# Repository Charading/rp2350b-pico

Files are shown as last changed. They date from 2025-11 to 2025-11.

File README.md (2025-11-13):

# RP2350B Pico Board

This is a custom RP2350B development board designed to match the **Raspberry Pi Pico** form factor.  
It keeps a similar form factor but is extended by a few pins, in order to break out all 8 analog gpio.

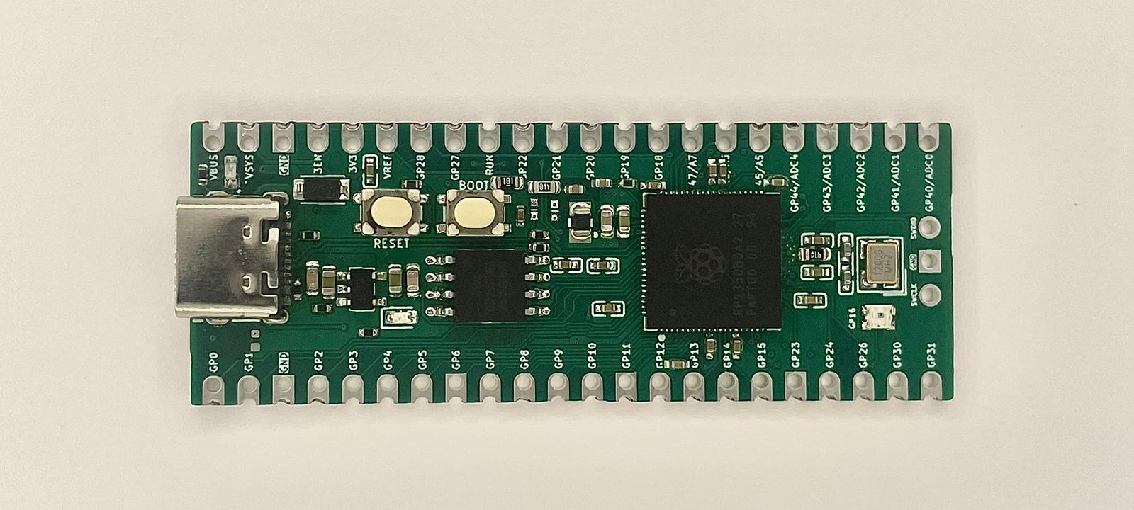
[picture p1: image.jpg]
assembled board


---

## Features
- **RP2350B microcontroller**
- **Pico-compatible pinout**
- **USB-C connector**
- **WS2812 RGB LED** on **GPIO16**
- **BOOT** and **RESET** buttons
- **Castellated edges** for module or breadboard use

---

## Notes
- The WS2812 LED on **GPIO16** can be controlled using any standard NeoPixel or WS2812 library.
- The board powers from **USB 5V (VBUS)** through a Schottky diode to **VSYS**,  
  then regulated down to **3.3V** for the MCU.
- Fully compatible with the **Raspberry Pi Pico SDK**, **MicroPython**, and **CircuitPython**.

### Expansion Board
I also created a small expansion board since it doesn't follow the exact layout as the original Pico.

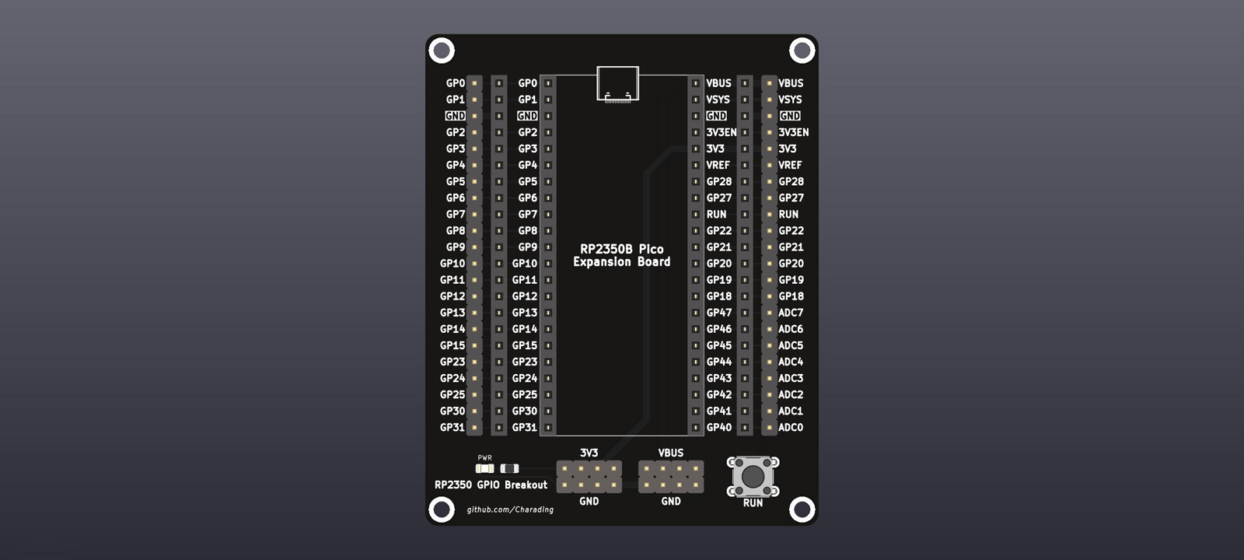
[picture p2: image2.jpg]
expansion board


---

Designed for experimentation and easy migration from RP2040 to RP2350 as I wanted more analog pins for a project.
Inspiration taken from  [pico-stretch](https://github.com/jvanderberg/pico-stretch) by [jvanderberg](https://github.com/jvanderberg)

---

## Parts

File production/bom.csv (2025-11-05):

Designator | Footprint | Quantity | Value | LCSC Part #
BOOT1, RESET1 | KEY-SMD_4P-L4.2-W3.2-P2.20-LS5.1-TL | 2 | K2-1808SN-A4SW-01 | C92589
C1, C13, C14, C16, C2, C36, C7, C8 | C0402 | 8 | 100nF | C1525
C10, C12 | C_0603 | 2 | 4.7uF | C19666
C11, C19 | C_0402 | 2 | 4.7uF | C23733
C15, C9 | C0402 | 2 | 100nF | C14663
C17, C18 | C0402 | 2 | 15pF | C1548
C22 | C_0402 | 1 | 100nF | C1525
C3, C4, C5, C6 | C0402 | 4 | 100nF
C37, C40 | C_0603 | 2 | 10uF | C19702
C38, C39 | C_0603 | 2 | 100nF | C14663
D1 | POWERDI-123_L2.8-W1.8-LS3.7-RD | 1 | ~ | C110493
D2, D3 | D0402-BI | 2 | RCLAMP0521P.TCT-MS | C3029033
D4 | LED_WS2812B-2020_PLCC4_2.0x2.0mm | 1 | WS2812B-2020
J1, J3 | Pico_22pin | 2 | Conn_01x32_MountingPin
J2 | PinHeader_1x03_P2.54mm_Vertical | 1 | Conn_01x03_Pin
L1 | IND-SMD_L2.0-W1.6_AOTA-B201610S3R3-101-T | 1 | ~ | C42411119
LED1 | Mars_LED_0603 | 1 | Red | C2286
PWR_LED1 | D_0603 | 1 | Red | C2286
R1, R4 | R_0402 | 2 | 5.1kΩ | C25905
R11 | R_0402 | 1 | 100kΩ | C25741
R12, R9 | R_0402 | 2 | 2kΩ | C4109
R14 | R_0402 | 1 | 10kΩ | C25744
R2, R3 | R_0402 | 2 | 33Ω | C25105
R28 | R_0603 | 1 | 1kΩ | C21190
R5 | R_0402 | 1 | 1kΩ | C11702
R6 | R0402 | 1 | 33Ω | C25105
R7 | R_0603 | 1 | 1Ω | C22936
R8 | R_0603 | 1 | 200Ω | C8218
TP1, TP2 | TestPoint_Pad_1.0x1.0mm | 2 | TestPoint
U1 | QFN-80_L10.0-W10.0-P0.40-TL-EP3.4 | 1 | ~ | C42415655
U3 | SOT-23-5_L3.0-W1.7-P0.95-LS2.8-BR | 1 | ~ | C427602
U4 | SOIC-8_L5.3-W5.3-P1.27-LS8.0-BL | 1 | Winbond W25Q128JVSIQ | C97521
U6 | SOIC-8_3.9x4.9mm_P1.27mm | 1 | ESP-PSRAM32
USB1 | USB-C-SMD_TYPE-C-6PIN-2MD-073 | 1 | ~ | C2765186
X1 | CRYSTAL-SMD_4P-L3.2-W2.5-BL | 1 | ~ | C20625731

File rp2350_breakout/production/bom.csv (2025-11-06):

Designator | Footprint | Quantity | Value | LCSC Part #
J1, J2, J3, J4, J5, J6 | Mars_Clean_Connector_01x22_PinHeader_2.54mm | 6 | Conn_01x32_MountingPin
PWR | 0805 | 1 | LED
R1 | R_0805 | 1 | R
SW1 | SW_TH_Tactile_Omron_B3F-102x | 1 | RUN

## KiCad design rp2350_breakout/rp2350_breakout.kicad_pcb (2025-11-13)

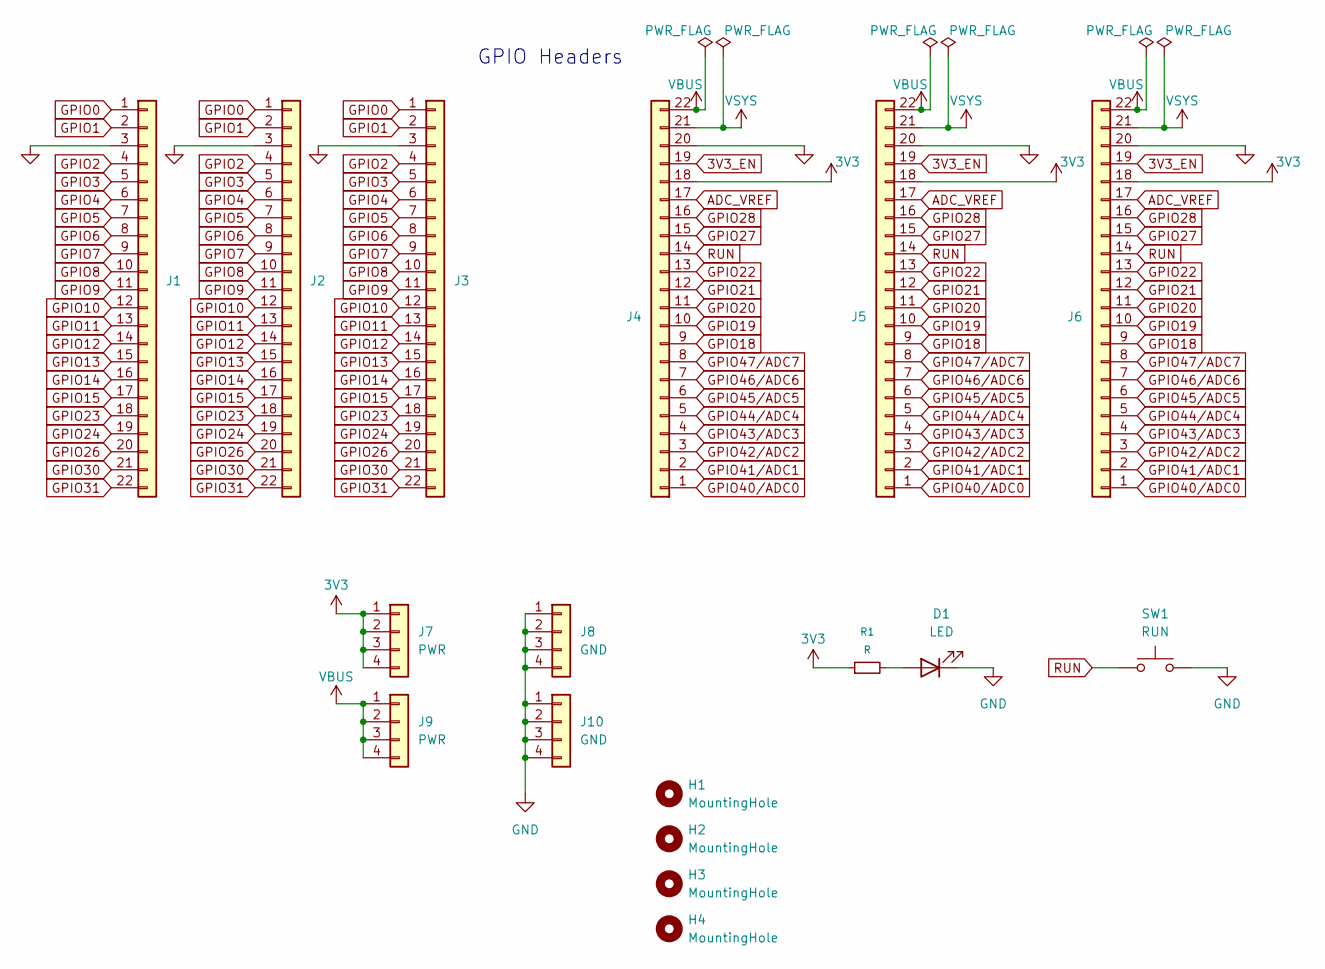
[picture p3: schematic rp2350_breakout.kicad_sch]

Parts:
D1: LED; LED_0805_2012Metric
H1, H2, H3, H4: MountingHole; MountingHole_2.2mm_M2
J1, J2, J3, J4, J5, J6: Conn_01x32_MountingPin; Mars_Clean_Connector_01x22_PinHeader_2.54mm
J7, J9: PWR; SWD_Debug_PinHeader_1x04_P2.54mm; Part Number 1-0401FBV0T
J8, J10: GND; SWD_Debug_PinHeader_1x04_P2.54mm; Part Number 1-0401FBV0T
R1: R; R_0805
SW1: RUN; SW_TH_Tactile_Omron_B3F-102x

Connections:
3V3: J4.18, J5.18, J6.18, J7.1, J7.2, J7.3, J7.4, R1.1
3V3_EN: J4.19, J5.19, J6.19
ADC_VREF: J4.17, J5.17, J6.17
GND: D1.1 (K), J1.3, J2.3, J3.3, J4.20, J5.20, J6.20, J8.1, J8.2, J8.3, J8.4, J10.1, J10.2, J10.3, J10.4, SW1.2; also elsewhere on the board
GPIO0: J1.1, J2.1, J3.1
GPIO1: J1.2, J2.2, J3.2
GPIO2: J1.4, J2.4, J3.4
GPIO3: J1.5, J2.5, J3.5
GPIO4: J1.6, J2.6, J3.6
GPIO5: J1.7, J2.7, J3.7
GPIO6: J1.8, J2.8, J3.8
GPIO7: J1.9, J2.9, J3.9
GPIO8: J1.10, J2.10, J3.10
GPIO9: J1.11, J2.11, J3.11
GPIO10: J1.12, J2.12, J3.12
GPIO11: J1.13, J2.13, J3.13
GPIO12: J1.14, J2.14, J3.14
GPIO13: J1.15, J2.15, J3.15
GPIO14: J1.16, J2.16, J3.16
GPIO15: J1.17, J2.17, J3.17
GPIO18: J4.9, J5.9, J6.9
GPIO19: J4.10, J5.10, J6.10
GPIO20: J4.11, J5.11, J6.11
GPIO21: J4.12, J5.12, J6.12
GPIO22: J4.13, J5.13, J6.13
GPIO23: J1.18, J2.18, J3.18
GPIO24: J1.19, J2.19, J3.19
GPIO26: J1.20, J2.20, J3.20
GPIO27: J4.15, J5.15, J6.15
GPIO28: J4.16, J5.16, J6.16
GPIO30: J1.21 (Pin_19), J2.21 (Pin_19), J3.21 (Pin_19)
GPIO31: J1.22 (Pin_20), J2.22 (Pin_20), J3.22 (Pin_20)
GPIO40/ADC0: J4.1, J5.1, J6.1
GPIO41/ADC1: J4.2, J5.2, J6.2
GPIO42/ADC2: J4.3, J5.3, J6.3
GPIO43/ADC3: J4.4, J5.4, J6.4
GPIO44/ADC4: J4.5, J5.5, J6.5
GPIO45/ADC5: J4.6, J5.6, J6.6
GPIO46/ADC6: J4.7, J5.7, J6.7
GPIO47/ADC7: J4.8, J5.8, J6.8
unnamed 40: D1.2 (A), R1.2; also elsewhere on the board
RUN: J4.14, J5.14, J6.14, SW1.1
VBUS: J4.22 (Pin_20), J5.22 (Pin_20), J6.22 (Pin_20), J9.1, J9.2, J9.3, J9.4
VSYS: J4.21 (Pin_19), J5.21 (Pin_19), J6.21 (Pin_19)

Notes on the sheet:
GPIO Headers

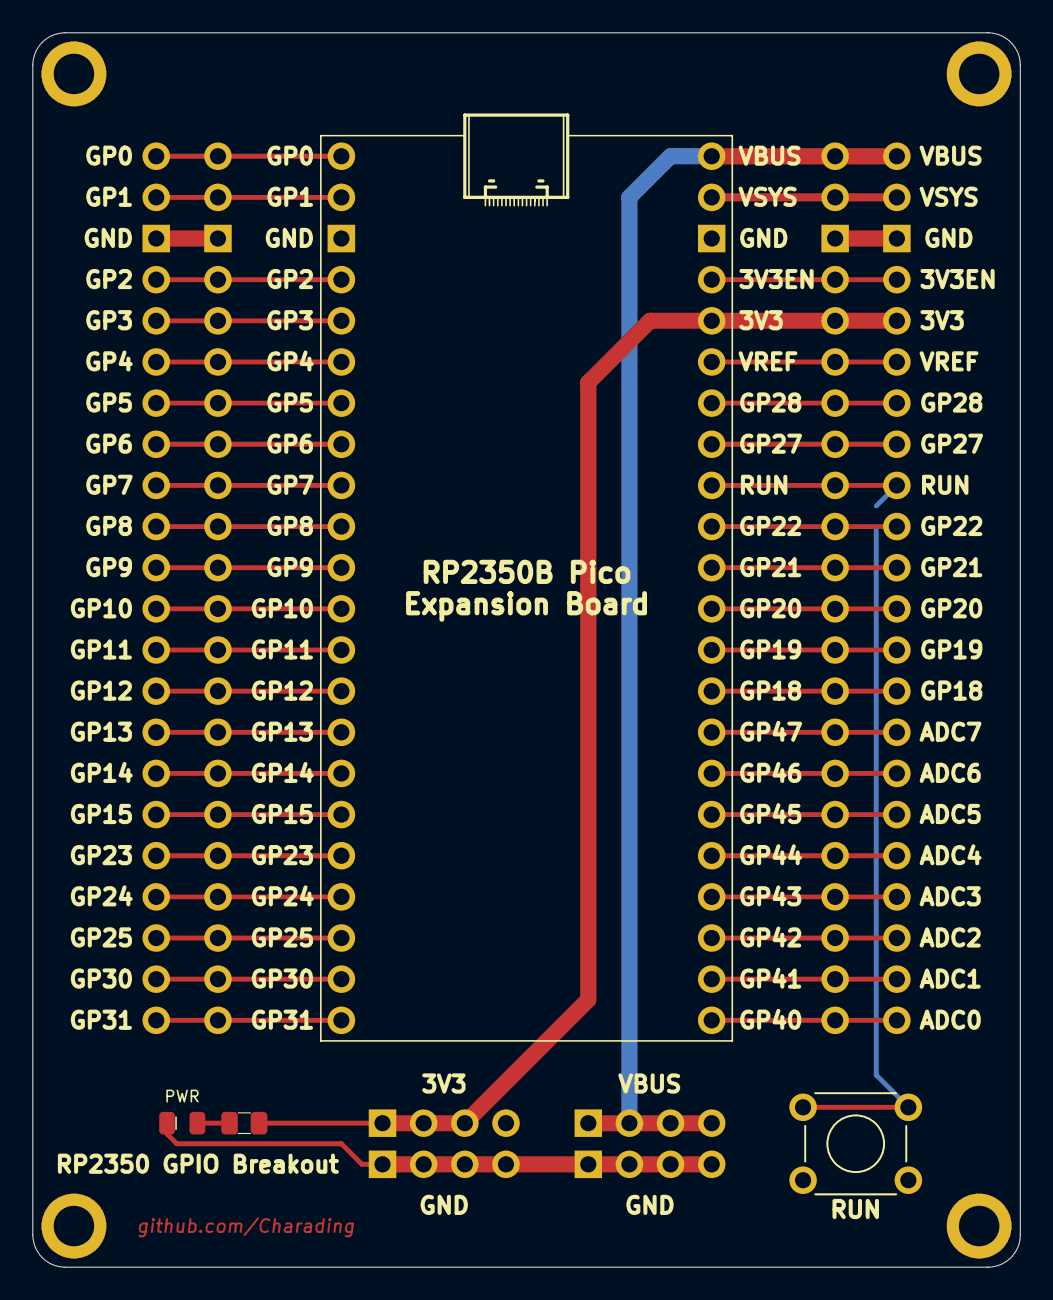
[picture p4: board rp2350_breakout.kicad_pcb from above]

Board: 2 copper layers, 61.0 x 76.2 mm, 17 parts (0 on the bottom side), 44 nets.

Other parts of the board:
PWR: LED; LED_0805_2012Metric

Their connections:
GND: PWR.1 (K); also elsewhere on the board
unnamed 40: PWR.2 (A); also elsewhere on the board

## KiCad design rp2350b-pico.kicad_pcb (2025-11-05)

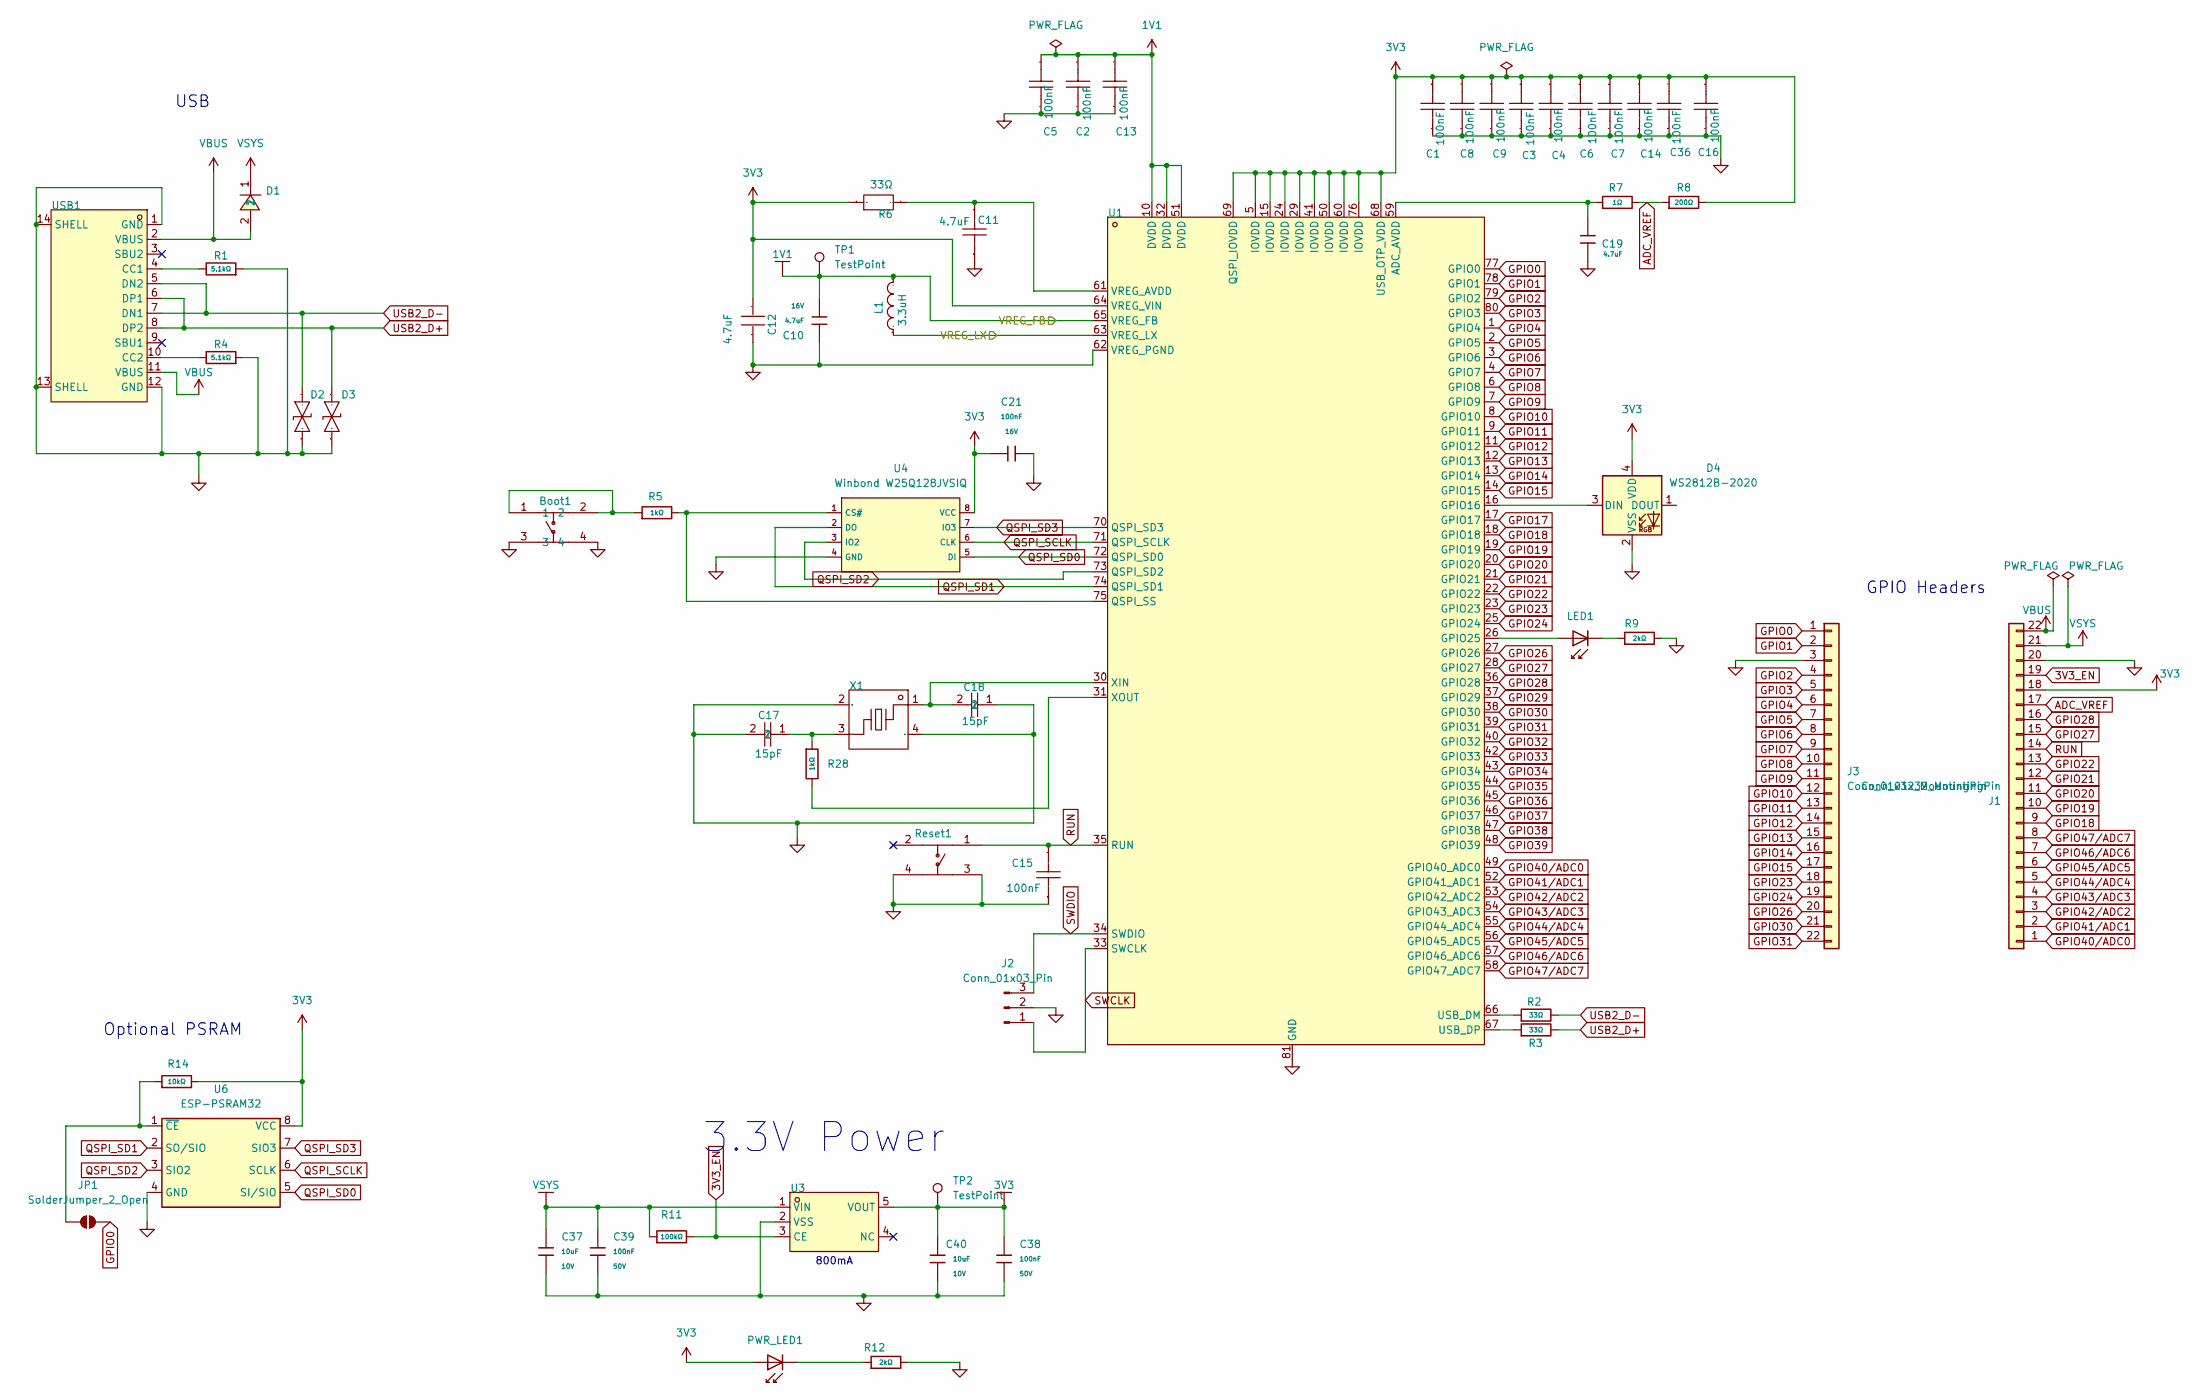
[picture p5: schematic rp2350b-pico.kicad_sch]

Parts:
Boot1: K2-1808SN-A4SW-01; KEY-SMD_4P-L4.2-W3.2-P2.20-LS5.1-TL; Manufacturer Part K2-1808SN-A4SW-01; LCSC Part Name 4.2mm*3.25mm
C1, C2, C3, C4, C5, C6, C7, C8, C13, C14, C16, C36: 100nF; C0402; Manufacturer Part CL05B104KO5NNNC; LCSC Part Name 100nF ±10% 16V
C9, C15: 100nF; C0402; Voltage Rating 50V; Manufacturer Part CC0603KRX7R9BB104; LCSC Part Name 100nF ±10% 50V
C10: 4.7uF; C_0603; Voltage Rated 16V; Tolerance ±10%; Part CL10A475KO8NNNC; LCSC C19666
C11: 4.7uF; Manufacturer Part CL05A475MP5NRNC; LCSC Part Name 4.7uF ±20% 10V
C12: 4.7uF; Manufacturer Part CL10A475KO8NNNC; LCSC Part Name 4.7uF ±10% 16V
C17, C18: 15pF; C0402; Manufacturer Part 0402CG150J500NT; LCSC Part Name 15pF ±5% 50V
C19: 4.7uF; C_0402; Voltage Rated 10V; Tolerance ±20%; Part CL05A475MP5NRNC; LCSC C23733
C21: 100nF; C_0402; Voltage Rated 16V; Tolerance ±10%; Part CL05B104KO5NNNC; LCSC C1525
C37, C40: 10uF; C_0603; Voltage Rated 10V; Tolerance ±10%; Part CL10A106KP8NNNC; LCSC C19702
C38, C39: 100nF; C_0603; Voltage Rated 50V; Tolerance ±10%; Part CC0603KRX7R9BB104; LCSC C14663
D1: POWERDI-123_L2.8-W1.8-LS3.7-RD; Manufacturer Part DFLS130L-7; LCSC Part Name 电压:30V 电流:1A
D2, D3: RCLAMP0521P.TCT-MS; D0402-BI; Manufacturer Part RCLAMP0521P.TCT-MS; LCSC Part Name 双向TVS 5V截止 4A峰值脉冲 丝印N
D4: WS2812B-2020; LED_WS2812B-2020_PLCC4_2.0x2.0mm
J1, J3: Conn_01x32_MountingPin; Pico_22pin
J2: Conn_01x03_Pin; PinHeader_1x03_P2.54mm_Vertical
JP1: SolderJumper_2_Open; JUMPER_SMD_1x2_tiny
L1: IND-SMD_L2.0-W1.6_AOTA-B201610S3R3-101-T; Manufacturer Part AOTA-B201610S3R3-101-T; LCSC Part Name AOTA-B201610S3R3-101-T
LED1: Red; Mars_LED_0603; Part KT-0603R; LCSC C2286
PWR_LED1: Red; D_0603; Part KT-0603R; LCSC C2286
R1, R4: 5.1kΩ; R_0402; Overload Voltage (Max) 50V; Tolerance ±1%; Part 0402WGF5101TCE; LCSC C25905
R2, R3: 33Ω; R_0402; Overload Voltage (Max) 50V; Tolerance ±1%; Part 0402WGF330JTCE; LCSC C25105
R5: 1kΩ; R_0402; Overload Voltage (Max) 50V; Tolerance ±1%; Part 0402WGF1001TCE; LCSC C11702
R6: 33Ω; R0402; Manufacturer Part 0402WGF330JTCE; LCSC Part Name 33Ω ±1% 62.5mW 厚膜电阻
R7: 1Ω; R_0603; Overload Voltage (Max) 75V; Tolerance ±1%; Part 0603WAF100KT5E; LCSC C22936
R8: 200Ω; R_0603; Overload Voltage (Max) 75V; Tolerance ±1%; Part 0603WAF2000T5E; LCSC C8218
R9, R12: 2kΩ; R_0402; Overload Voltage (Max) 50V; Tolerance ±1%; Part 0402WGF2001TCE; LCSC C4109
R11: 100kΩ; R_0402; Overload Voltage (Max) 50V; Tolerance ±1%; Part 0402WGF1003TCE; LCSC C25741
R14: 10kΩ; R_0402; Overload Voltage (Max) 50V; Tolerance ±1%; Part 0402WGF1002TCE; LCSC C25744
R28: 1kΩ; R_0603; Overload Voltage (Max) 75V; Tolerance ±1%; Part 0603WAF1001T5E; LCSC C21190
Reset1: K2-1808SN-A4SW-01; KEY-SMD_4P-L4.2-W3.2-P2.20-LS5.1-TL; Manufacturer Part K2-1808SN-A4SW-01; LCSC Part Name 4.2mm*3.25mm
TP1, TP2: TestPoint; TestPoint_Pad_1.0x1.0mm
U1: QFN-80_L10.0-W10.0-P0.40-TL-EP3.4; Manufacturer Part RP2350B; LCSC Part Name RP2350B
U3: SOT-23-5_L3.0-W1.7-P0.95-LS2.8-BR; Manufacturer Part ME6217C33M5G; LCSC Part Name ME6217C33M5G
U4: Winbond W25Q128JVSIQ; SOIC-8_L5.3-W5.3-P1.27-LS8.0-BL; Part W25Q128JVSIQ; LCSC C97521
U6: ESP-PSRAM32; SOIC-8_3.9x4.9mm_P1.27mm
USB1: USB-C-SMD_TYPE-C-6PIN-2MD-073; Manufacturer Part TYPE-C 16PIN 2MD(073); LCSC Part Name Type-C 母 卧贴
X1: Manufacturer Part ABM8-272-T3; LCSC Part Name ABM8-272-T3

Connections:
1V1: C2.1, C5.1, C10.2, C13.2, L1.2, TP1.1, U1.10 (DVDD), U1.32 (DVDD), U1.51 (DVDD), U1.65 (VREG_FB)
3V3: C1.1, C3.1, C4.1, C6.1, C7.1, C8.2, C9.2, C12.2, C14.2, C16.1, C21.1, C36.2, C38.1, C40.1, D4.4 (VDD), J1.18, PWR_LED1.2, R6.1, R8.2, R14.2, TP2.1, U1.5 (IOVDD), U1.15 (IOVDD), U1.24 (IOVDD), U1.29 (IOVDD), U1.41 (IOVDD), U1.50 (IOVDD), U1.60 (IOVDD), U1.64 (VREG_VIN), U1.68 (USB_OTP_VDD), U1.69 (QSPI_IOVDD), U1.76 (IOVDD), U3.5 (VOUT), U4.8 (VCC), U6.8 (VCC); also elsewhere on the board
3V3_EN: J1.19, R11.2, U3.3 (CE)
/VREG_LX: L1.1, U1.63 (VREG_LX)
ADC_VREF: J1.17, R7.2, R8.1
GND: Boot1.3, Boot1.4, C1.2, C2.2, C3.2, C4.2, C5.2, C6.2, C7.2, C8.1, C9.1, C10.1, C11.1, C12.1, C13.1, C14.1, C15.1, C16.2, C17.2, C18.1, C19.2, C21.2, C36.1, C37.2, C38.2, C39.2, C40.2, D2.1, D3.1, D4.2 (VSS), J1.20, J2.2, J3.3, R1.1, R4.1, R9.2, R12.2, Reset1.3, Reset1.4, U1.62 (VREG_PGND), U1.81 (GND), U3.2 (VSS), U4.4 (GND), U6.4 (GND), USB1.1 (GND), USB1.12 (GND), USB1.13 (SHELL), USB1.14 (SHELL), X1.2 (GND), X1.4 (GND); also elsewhere on the board
GPIO0: J3.1, JP1.2 (B), U1.77 (GPIO0)
GPIO1: J3.2, U1.78 (GPIO1)
GPIO2: J3.4, U1.79 (GPIO2)
GPIO3: J3.5, U1.80 (GPIO3)
GPIO4: J3.6, U1.1 (GPIO4)
GPIO5: J3.7, U1.2 (GPIO5)
GPIO6: J3.8, U1.3 (GPIO6)
GPIO7: J3.9, U1.4 (GPIO7)
GPIO8: J3.10, U1.6 (GPIO8)
GPIO9: J3.11, U1.7 (GPIO9)
GPIO10: J3.12, U1.8 (GPIO10)
GPIO11: J3.13, U1.9 (GPIO11)
GPIO12: J3.14, U1.11 (GPIO12)
GPIO13: J3.15, U1.12 (GPIO13)
GPIO14: J3.16, U1.13 (GPIO14)
GPIO15: J3.17, U1.14 (GPIO15)
GPIO17: U1.17 (GPIO17)
GPIO18: J1.9, U1.18 (GPIO18)
GPIO19: J1.10, U1.19 (GPIO19)
GPIO20: J1.11, U1.20 (GPIO20)
GPIO21: J1.12, U1.21 (GPIO21)
GPIO22: J1.13, U1.22 (GPIO22)
GPIO23: J3.18, U1.23 (GPIO23)
GPIO24: J3.19, U1.25 (GPIO24)
GPIO26: J3.20, U1.27 (GPIO26)
GPIO27: J1.15, U1.28 (GPIO27)
GPIO28: J1.16, U1.36 (GPIO28)
GPIO29: U1.37 (GPIO29)
GPIO30: J3.21 (Pin_19), U1.38 (GPIO30)
GPIO31: J3.22 (Pin_20), U1.39 (GPIO31)
GPIO32: U1.40 (GPIO32)
GPIO33: U1.42 (GPIO33)
GPIO34: U1.43 (GPIO34)
GPIO35: U1.44 (GPIO35)
GPIO36: U1.45 (GPIO36)
GPIO37: U1.46 (GPIO37)
GPIO38: U1.47 (GPIO38)
GPIO39: U1.48 (GPIO39)
GPIO40/ADC0: J1.1, U1.49 (GPIO40_ADC0)
GPIO41/ADC1: J1.2, U1.52 (GPIO41_ADC1)
GPIO42/ADC2: J1.3, U1.53 (GPIO42_ADC2)
GPIO43/ADC3: J1.4, U1.54 (GPIO43_ADC3)
GPIO44/ADC4: J1.5, U1.55 (GPIO44_ADC4)
GPIO45/ADC5: J1.6, U1.56 (GPIO45_ADC5)
GPIO46/ADC6: J1.7, U1.57 (GPIO46_ADC6)
GPIO47/ADC7: J1.8, U1.58 (GPIO47_ADC7)
unnamed: Boot1.1, Boot1.2, R5.1
unnamed: C17.1, R28.1, X1.3
unnamed: D4.3 (DIN), U1.16 (GPIO16)
unnamed: JP1.1 (A), R14.1, U6.1 (~CE)
unnamed: LED1.1, R9.1
unnamed: PWR_LED1.1, R12.1
unnamed: C19.1, R7.1, U1.59 (ADC_AVDD)
unnamed: LED1.2, U1.26 (GPIO25)
unnamed: R5.2, U1.75 (QSPI_SS), U4.1 (CS#)
unnamed: R2.1, U1.66 (USB_DM)
unnamed: R3.1, U1.67 (USB_DP)
unnamed: C11.2, R6.2, U1.61 (VREG_AVDD)
unnamed: C18.2, U1.30 (XIN), X1.1
unnamed: R28.2, U1.31 (XOUT)
unnamed: R1.2, USB1.4 (CC1)
unnamed: R4.2, USB1.10 (CC2)
QSPI_SCLK: U1.71 (QSPI_SCLK), U4.6 (CLK), U6.6 (SCLK)
QSPI_SD0: U1.72 (QSPI_SD0), U4.5 (DI), U6.5 (SI/SIO)
QSPI_SD1: U1.74 (QSPI_SD1), U4.2 (DO), U6.2 (SO/SIO)
QSPI_SD2: U1.73 (QSPI_SD2), U4.3 (IO2), U6.3 (SIO2)
QSPI_SD3: U1.70 (QSPI_SD3), U4.7 (IO3), U6.7 (SIO3)
RUN: C15.2, J1.14, Reset1.1, U1.35 (RUN)
SWCLK: J2.1, U1.33 (SWCLK)
SWDIO: J2.3, U1.34 (SWDIO)
USB2_D+: D3.2, R3.2, USB1.6 (DP1), USB1.8 (DP2)
USB2_D-: D2.2, R2.2, USB1.5 (DN2), USB1.7 (DN1)
VBUS: D1.2, J1.22 (Pin_20), USB1.2 (VBUS), USB1.11 (VBUS)
VSYS: C37.1, C39.1, D1.1, J1.21 (Pin_19), R11.1, U3.1 (VIN)

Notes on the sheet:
Optional PSRAM
3.3V Power
GPIO Headers
USB
800mA

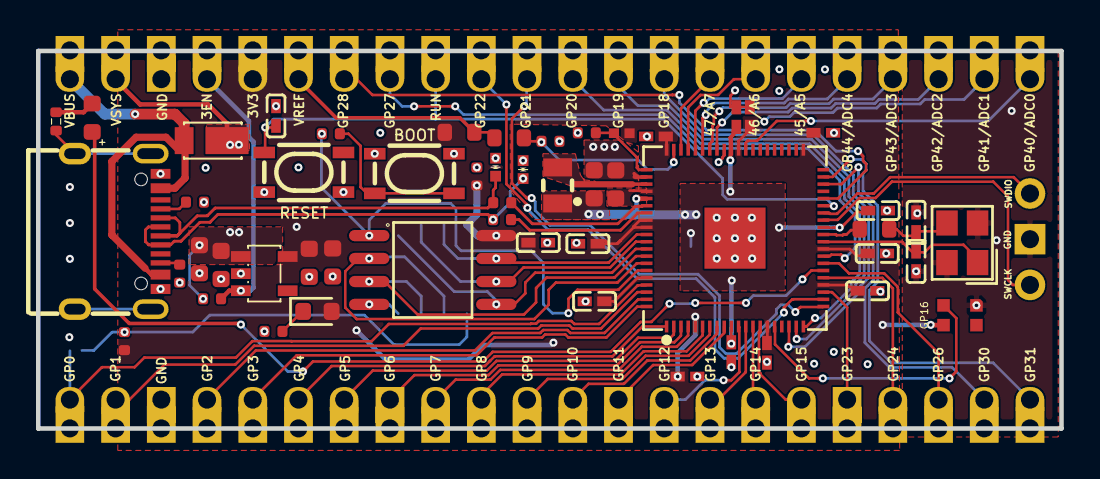
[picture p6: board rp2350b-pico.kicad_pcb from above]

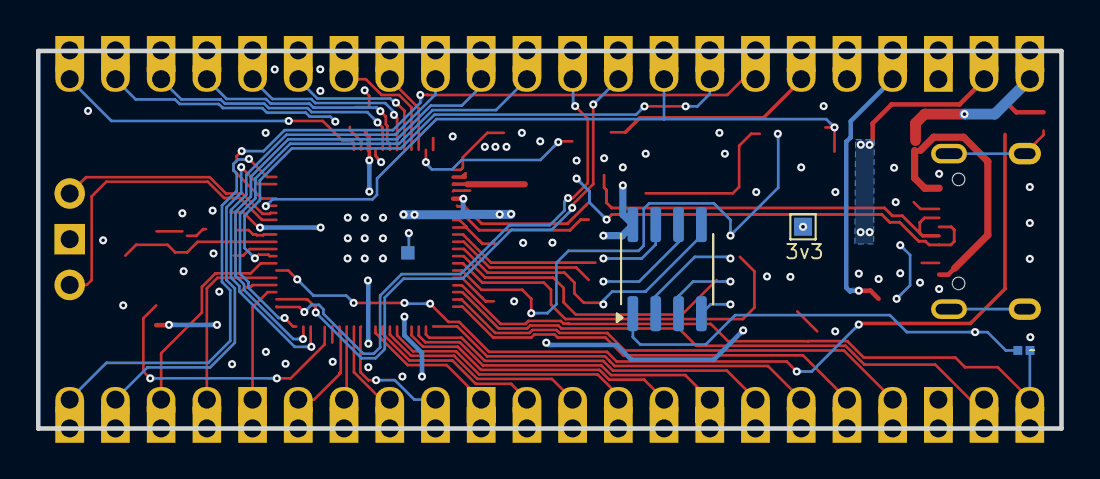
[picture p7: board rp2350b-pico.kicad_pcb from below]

Board: 4 copper layers, 56.8 x 21.0 mm, 59 parts (4 on the bottom side), 70 nets.

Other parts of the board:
C22: 100nF; C_0402

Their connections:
3V3: C22.1; also elsewhere on the board
GND: C22.2; also elsewhere on the board

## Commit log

2025-11-05 Revise README to enhance board description
    Updated the description to clarify the board's features and inspiration.
2025-11-06 designed gpio expansion board
    [bom.csv, designators.csv, positions.csv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]
2025-11-13 updated readme to include expansion board
    [rp2350_breakout.kicad_pcb]
